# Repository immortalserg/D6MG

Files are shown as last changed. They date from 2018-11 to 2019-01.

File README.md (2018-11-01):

# D6MG shield
## Палата расширения для OrangePi PC
### Описание
- питание от источника питания 12 В
- часы реального времени i2c DS3132
- 1-wire на шине i2c DS2482
- RS485
- CAN
- выведены порты LAN и 2 USB вниз
- 315/433 МГц приемники - передатчики (2 микросхемы SYN470R, 2 микросхемы SYN115)
- nrf24l01+
- zigbee (CC2530 с усилителем CC2591)
- LoRa RFM95 (модуль)
- RFM69 (модуль)
- 16 каналов ШИМ (PCA9685)
- 16 каналов входы/выходы (MCP27013)
- 16 каналов DAC (4 микросхемы MCP4728)
- 16 каналов ADC (4 микросхемы MCP3424)
- боковой разъем c шиной i2c для подключения модулей расширения Wiren Board
- USB - UART0 СP2102
- управляемый по GPIO кулер охлаждения

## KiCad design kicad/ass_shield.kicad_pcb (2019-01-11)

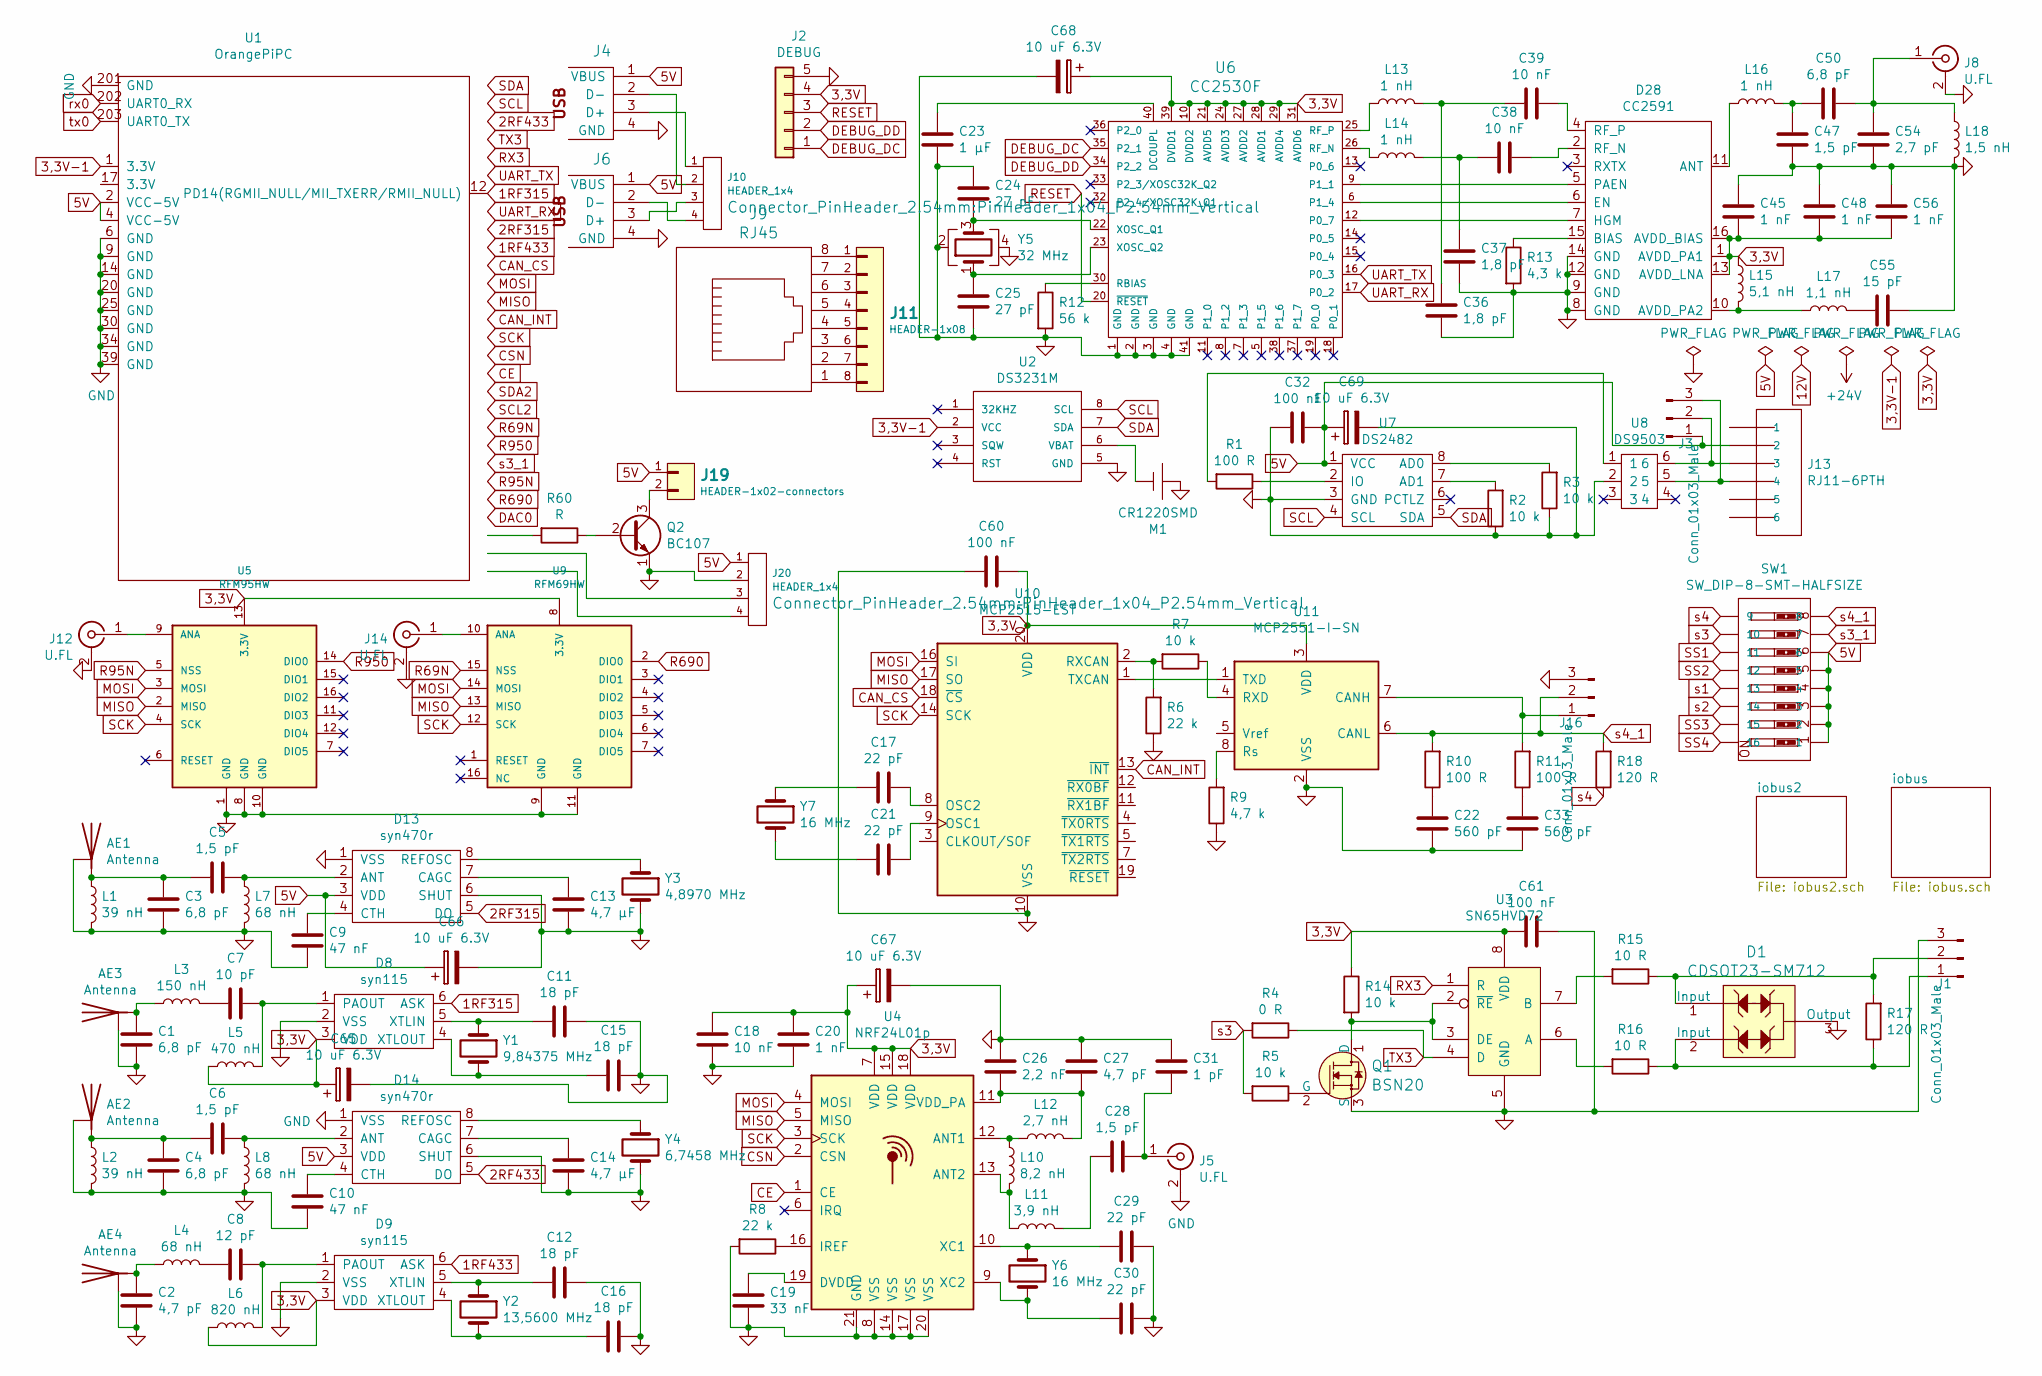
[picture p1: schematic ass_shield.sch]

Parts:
AE1, AE2, AE3, AE4: Antenna; U.FL_Hirose_U.FL-R-SMT-1_Vertical
C1, C3, C4, C50: 6,8 pF; C_0402_1005Metric
C2, C27: 4,7 pF; C_0402_1005Metric
C5, C6, C28, C47: 1,5 pF; C_0402_1005Metric
C7: 10 pF; C_0402_1005Metric
C8: 12 pF; C_0402_1005Metric
C9, C10: 47 nF; C_0402_1005Metric
C11, C12, C15, C16: 18 pF; C_0402_1005Metric
C13, C14: 4,7 µF; C_0402_1005Metric
C17, C21, C29, C30: 22 pF; C_0402_1005Metric
C18, C38, C39: 10 nF; C_0402_1005Metric
C19: 33 nF; C_0402_1005Metric
C20, C45, C48, C56: 1 nF; C_0402_1005Metric
C22, C33: 560 pF; C_0402_1005Metric
C23: 1 µF; C_0402_1005Metric
C24, C25: 27 pF; C_0402_1005Metric
C26: 2,2 nF; C_0402_1005Metric
C31: 1 pF; C_0402_1005Metric
C32, C60, C61: 100 nF; C_0402_1005Metric
C36, C37: 1,8 pF; C_0402_1005Metric
C54: 2,7 pF; C_0402_1005Metric
C55: 15 pF; C_0402_1005Metric
C65, C66, C67, C68, C69: 10 uF 6.3V; C_1206_3216Metric
D1: CDSOT23-SM712; SOT-23; MPN CDSOT23-SM712; Digi-Key_PN CDSOT23-SM712CT-ND
D8, D9: syn115; SOT-23-6_Handsoldering
D13, D14: syn470r; SSOP-8_3.95x5.21x3.27mm_P1.27mm
D28: CC2591; QFN-16-1EP_4x4mm_P0.65mm_EP2.5x2.5mm
J1, J3, J16: Conn_01x03_Male; pt_1,5-3-3,5-h
J2: DEBUG; PinHeader_1x05_P1.27mm_Vertical
J4, J6: USB; conn_usb_A-vert
J5, J8, J12, J14: U.FL; U.FL_Hirose_U.FL-R-SMT-1_Vertical
J9: RJ45; rj45-shield
J10, J20: HEADER_1x4; PinHeader_1x04_P2.54mm_Vertical
J11: HEADER-1x08; PinHeader_2x04_P2.54mm_Vertical
J13: RJ11-6PTH; rj11-shield
J19: HEADER-1x02-connectors; PinHeader_1x02_P2.54mm_Vertical
L1, L2: 39 nH; L_0402_1005Metric
L3: 150 nH; L_0402_1005Metric
L4, L7, L8: 68 nH; L_0402_1005Metric
L5: 470 nH; L_0603_1608Metric
L6: 820 nH; L_0805_2012Metric
L10: 8,2 nH; L_0402_1005Metric
L11: 3,9 nH; L_0402_1005Metric
L12: 2,7 nH; L_0402_1005Metric
L13, L14, L16: 1 nH; L_0402_1005Metric
L15: 5,1 nH; L_0402_1005Metric
L17: 1,1 nH; L_0402_1005Metric
L18: 1,5 nH; L_0402_1005Metric
M1: CR1220SMD; cr1220_smd
Q1: BSN20; SOT-23; MPN BS170; Digi-Key_PN BS170-ND
Q2: BC107; SOT-23
R1, R10, R11: 100 R; R_0402_1005Metric
R2, R3, R5, R7, R14: 10 k; R_0402_1005Metric
R4: 0 R; R_0402_1005Metric
R6, R8: 22 k; R_0402_1005Metric
R9: 4,7 k; R_0402_1005Metric
R12: 56 k; R_0402_1005Metric
R13: 4,3 k; R_0402_1005Metric
R15, R16: 10 R; R_0402_1005Metric
R17, R18: 120 R; R_0402_1005Metric
R60: R; R_0402_1005Metric
SW1: SW_DIP-8-SMT-HALFSIZE; DIPSWITCH-08-50MIL
U1: OrangePiPC
U2: DS3231M; SO-8_5.3x6.2mm_P1.27mm
U3: SN65HVD72; SOIC-8_3.9x4.9mm_P1.27mm
U4: NRF24L01p; QFN-20-1EP_4x4mm_P0.5mm_EP2.5x2.5mm
U5: RFM95HW; RFM69HW_SMD_Handsoldering
U6: CC2530F; QFN-40-1EP_6x6mm_P0.5mm_EP4.6x4.6mm
U7: DS2482; SOIC-8_3.9x4.9mm_P1.27mm
U8: DS9503; TSOT-23-6
U9: RFM69HW; RFM69HW_SMD_Handsoldering
U10: MCP2515-EST; TSSOP-20_4.4x6.5mm_P0.65mm
U11: MCP2551-I-SN; SOIC-8_3.9x4.9mm_P1.27mm
Y1: 9,84375 MHz; Crystal_HC49-4H_Vertical
Y2: 13,5600 MHz; Crystal_HC49-4H_Vertical
Y3: 4,8970 MHz; Crystal_HC49-4H_Vertical
Y4: 6,7458 MHz; Crystal_HC49-4H_Vertical
Y5: 32 MHz; Crystal_SMD_3225-4Pin_3.2x2.5mm
Y6, Y7: 16 MHz; Crystal_SMD_3215-2Pin_3.2x1.5mm

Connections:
1RF315: D8.6 (ASK), U1.12 (PD14(RGMII_NULL/MII_TXERR/RMII_NULL))
1RF433: D9.6 (ASK), U1.16
2RF315: D13.5 (DO), U1.15
2RF433: D14.5 (DO), U1.7
3,3V: C18.1, C20.1, C45.1, C48.1, C56.1, C60.1, C61.2, C65.1, C67.1, C68.1, D8.3 (VDD), D9.3 (VDD), D28.1 (AVDD_PA1), D28.13 (AVDD_LNA), D28.16 (AVDD_BIAS), J2.4, L5.1, L6.1, L15.1, R14.1, U3.8 (VDD), U4.7 (VDD), U4.15 (VDD), U4.18 (VDD), U5.13 (3.3V), U6.10 (DVDD2), U6.21 (AVDD5), U6.24 (AVDD3), U6.27 (AVDD2), U6.28 (AVDD1), U6.29 (AVDD4), U6.31 (AVDD6), U6.39 (DVDD1), U9.8 (3.3V), U10.20 (VDD), U11.3 (VDD); also elsewhere on the board
3,3V-1: U1.1 (3.3V), U2.2 (VCC)
5V: C32.1, C66.1, C69.1, D13.3 (VDD), D14.3 (VDD), J3.1, J4.1 (VBUS), J6.1 (VBUS), J13.2, J19.1, J20.1, SW1.1, SW1.2, SW1.3, SW1.4, SW1.5, SW1.6, U1.2 (VCC-5V), U1.4 (VCC-5V), U7.1 (VCC); also elsewhere on the board
CAN_CS: U1.18, U10.18 (~CS)
CAN_INT: U1.22, U10.13 (~INT)
CE: U1.26, U4.1 (CE)
CSN: U1.24, U4.2 (CSN)
DAC0: U1.36; also elsewhere on the board
DEBUG_DC: J2.1, U6.35 (P2_1)
DEBUG_DD: J2.2, U6.34 (P2_2)
GND: AE1.2 (GND), AE2.2 (GND), AE3.2 (GND), AE4.2 (GND), C1.1, C2.1, C3.2, C4.2, C9.2, C10.2, C11.1, C12.1, C13.1, C14.1, C15.1, C16.1, C18.2, C19.2, C20.2, C22.1, C23.2, C24.1, C25.2, C26.1, C27.1, C29.1, C30.1, C31.1, C32.2, C33.1, C36.2, C37.2, C45.2, C47.1, C48.2, C54.1, C55.1, C56.2, C60.2, C61.1, C65.2, C66.2, C67.2, C68.2, C69.2, D1.3 (Output), D8.2 (VSS), D9.2 (VSS), D13.1 (VSS), D13.6 (SHUT), D14.1 (VSS), D14.6 (SHUT), D28.8 (GND), D28.9 (GND), D28.12 (GND), D28.14 (GND), J1.3, J2.5, J4.4 (GND), J5.2 (Ext), J6.4 (GND), J8.2 (Ext), J12.2 (Ext), J14.2 (Ext), J16.3, J20.2, L1.2, L2.2, L7.2, L8.2, L18.2, M1.2 (+), Q1.3 (S), Q2.1 (E), R2.1, R3.1, R6.1, R8.2, R9.1, R12.2, R13.2, U1.6 (GND), U1.9 (GND), U1.14 (GND), U1.20 (GND), U1.25 (GND), U1.30 (GND), U1.34 (GND), U1.39 (GND), U1.201 (GND), U2.5 (GND), U3.5 (GND), U4.8 (VSS), U4.14 (VSS), U4.17 (VSS), U4.20 (VSS), U4.21 (GND), U5.1 (GND), U5.8 (GND), U5.10 (GND), U6.1 (GND), U6.2 (GND), U6.3 (GND), U6.4 (GND), U6.41 (GND), U7.3 (GND), U8.2, U9.9 (GND), U9.11 (GND), U10.10 (VSS), U11.2 (VSS), Y3.2, Y4.2, Y5.2, Y5.4; also elsewhere on the board
MISO: U1.21, U4.5 (MISO), U5.2 (MISO), U9.13 (MISO), U10.17 (SO)
MOSI: U1.19, U4.4 (MOSI), U5.3 (MOSI), U9.14 (MOSI), U10.16 (SI)
unnamed: AE1.1 (A), C3.1, C5.2, L1.1
unnamed: AE2.1 (A), C4.1, C6.2, L2.1
unnamed: AE3.1 (A), C1.2, L3.1
unnamed: AE4.1 (A), C2.2, L4.1
unnamed: C5.1, D13.2 (ANT), L7.1
unnamed: C6.1, D14.2 (ANT), L8.1
unnamed: C7.1, D8.1 (PAOUT), L5.2
unnamed: C7.2, L3.2
unnamed: C8.1, D9.1 (PAOUT), L6.2
unnamed: C8.2, L4.2
unnamed: C9.1, D13.4 (CTH)
unnamed: C10.1, D14.4 (CTH)
unnamed: C11.2, D8.5 (XTLIN), Y1.1
unnamed: C12.2, D9.5 (XTLIN), Y2.1
unnamed: C13.2, D13.7 (CAGC)
unnamed: C14.2, D14.7 (CAGC)
unnamed: C15.2, D8.4 (XTLOUT), Y1.2
unnamed: C16.2, D9.4 (XTLOUT), Y2.2
unnamed: C17.1, U10.8 (OSC2)
unnamed: C17.2, Y7.1
unnamed: C19.1, U4.19 (DVDD)
unnamed: C21.1, U10.9 (OSC1)
unnamed: C21.2, Y7.2
unnamed: C22.2, R10.1
unnamed: C23.1, U6.40 (DCOUPL)
unnamed: C24.2, U6.22 (XOSC_Q1), Y5.3
unnamed: C25.1, U6.23 (XOSC_Q2), Y5.1
unnamed: C26.2, C27.2, L12.2, U4.11 (VDD_PA)
unnamed: C28.1, C31.2, J5.1 (In)
unnamed: C28.2, L11.2
unnamed: C29.2, U4.10 (XC1), Y6.1
unnamed: C30.2, U4.9 (XC2), Y6.2
unnamed: C33.2, R11.1
unnamed: C36.1, C39.2, L13.2
unnamed: C37.1, C38.2, L14.2
unnamed: C38.1, D28.2 (RF_N)
unnamed: C39.1, D28.4 (RF_P)
unnamed: C47.2, C50.2, L16.2
unnamed: C50.1, C54.2, J8.1 (In), L18.1
unnamed: C55.2, L17.2
unnamed: D1.1 (Input), J1.2, R15.1, R17.2
unnamed: D1.2 (Input), J1.1, R16.1, R17.1
unnamed: D13.8 (REFOSC), Y3.1
unnamed: D14.8 (REFOSC), Y4.1
unnamed: D28.5 (PAEN), U6.9 (P1_1)
unnamed: D28.6 (EN), U6.6 (P1_4)
unnamed: D28.7 (HGM), U6.12 (P0_7)
unnamed: D28.10 (AVDD_PA2), L15.2, L17.1
unnamed: D28.11 (ANT), L16.1
unnamed: D28.15 (BIAS), R13.1
unnamed: J4.3 (D+), J10.1
unnamed: J4.2 (D-), J10.2
unnamed: J6.3 (D+), J10.3
unnamed: J6.2 (D-), J10.4
unnamed: J9.8, J11.1
unnamed: J9.7, J11.2
unnamed: J9.6, J11.3
unnamed: J9.5, J11.4
unnamed: J9.4, J11.5
unnamed: J9.3, J11.6
unnamed: J9.2, J11.7
unnamed: J9.1, J11.8
unnamed: J12.1 (In), U5.9 (ANA)
unnamed: J3.2, J13.3, U8.6
unnamed: J3.3, J13.4, U8.5
unnamed: J14.1 (In), U9.10 (ANA)
unnamed: J16.1, R11.2, U11.7 (CANH)
unnamed: J19.2, Q2.3 (C)
unnamed: J20.3, U1.38
unnamed: J20.4, U1.40
unnamed: L10.1, L12.1, U4.12 (ANT1)
unnamed: L10.2, L11.1, U4.13 (ANT2)
unnamed: L13.1, U6.25 (RF_P)
unnamed: L14.1, U6.26 (RF_N)
unnamed: M1.1 (-), U2.6 (VBAT)
unnamed: Q1.1 (D), R14.2, U3.2 (~RE), U3.3 (DE)
unnamed: Q1.2 (G), R5.1
unnamed: Q2.2 (B), R60.1
unnamed: R1.1, U7.2 (IO)
unnamed: R1.2, U8.1
unnamed: R2.2, U7.7 (AD1)
unnamed: R3.2, U7.8 (AD0)
unnamed: R6.2, R7.2, U10.2 (RXCAN)
unnamed: R7.1, U11.4 (RXD)
unnamed: R8.1, U4.16 (IREF)
unnamed: R9.2, U11.8 (Rs)
unnamed: R12.1, U6.30 (RBIAS)
unnamed: R15.2, U3.7 (B)
unnamed: R16.2, U3.6 (A)
unnamed: R60.2, U1.37
unnamed: U10.1 (TXCAN), U11.1 (TXD)
R69N: U1.29, U9.15 (NSS)
R95N: U1.33, U5.5 (NSS)
R690: U1.35, U9.2 (DIO0)
R950: U1.31, U5.14 (DIO0)
RESET: J2.3, U6.20 (~RESET)
RX3: U1.10, U3.1 (R)
SCK: U1.23, U4.3 (SCK), U5.4 (SCK), U9.12 (SCK), U10.14 (SCK)
SCL: U1.5, U2.8 (SCL), U7.4 (SCL); also elsewhere on the board
SCL2: U1.28; also elsewhere on the board
SDA: U1.3, U2.7 (SDA), U7.5 (SDA); also elsewhere on the board
SDA2: U1.27; also elsewhere on the board
SS1: SW1.11; also elsewhere on the board
SS2: SW1.12; also elsewhere on the board
SS3: SW1.15; also elsewhere on the board
SS4: SW1.16; also elsewhere on the board
TX3: R4.1, U1.8, U3.4 (D)
UART_RX: U1.13, U6.17 (P0_2)
UART_TX: U1.11, U6.16 (P0_3)
rx0: U1.202 (UART0_RX); also elsewhere on the board
s1: SW1.13; also elsewhere on the board
s2: SW1.14; also elsewhere on the board
s3: R4.2, R5.2, SW1.10
s3_1: SW1.7, U1.32
s4: R18.1, SW1.9
s4_1: J16.2, R10.2, R18.2, SW1.8, U11.6 (CANL)
tx0: U1.203 (UART0_TX); also elsewhere on the board

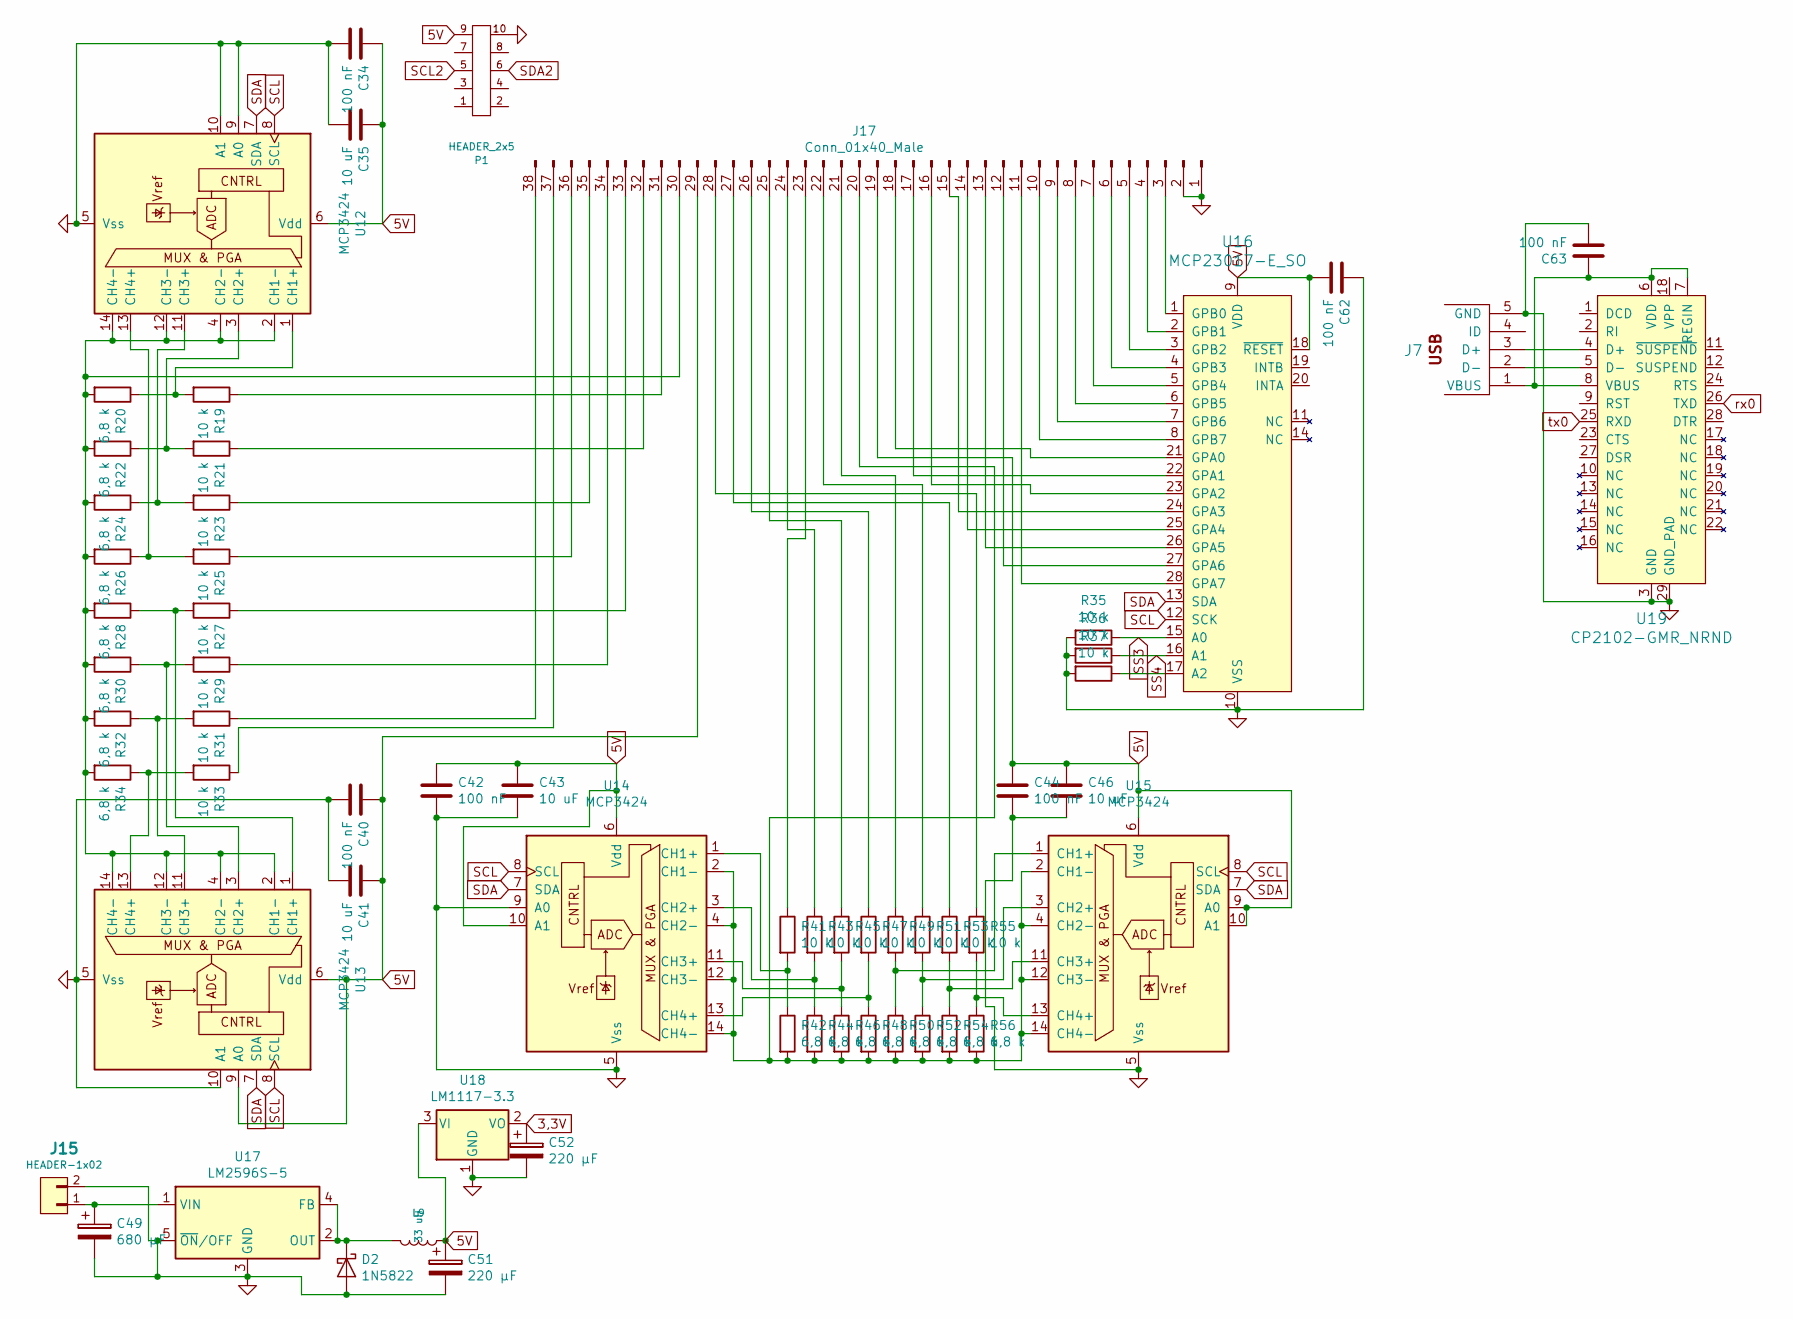
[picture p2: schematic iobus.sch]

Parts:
C34, C40, C42, C44, C62, C63: 100 nF; C_0402_1005Metric
C35, C41, C43, C46: 10 uF; C_0402_1005Metric
C49: 680 µF; CP_Elec_10x10
C51: 220 µF; CP_Elec_10x10
C52: 220 µF; C_1210_3225Metric
D2: 1N5822; D_SMC
J7: USBMINI; USB_Micro-B_Wuerth_614105150721_Vertical
J15: HEADER-1x02; mkds_1,5-2
J17: Conn_01x40_Male; PinHeader_2x19_P2.54mm_Vertical
L9: 33 uH; L_Bourns_SRR1260
P1: HEADER_2x5; PinSocket_2x05_P2.54mm_Horizontal
R19, R21, R23, R25, R27, R29, R31, R33, R35, R36, R37, R41, R43, R45, R47, R49, R51, R53, R55: 10 k; R_0402_1005Metric
R20, R22, R24, R26, R28, R30, R32, R34, R42, R44, R46, R48, R50, R52, R54, R56: 6,8 k; R_0402_1005Metric
U12, U13, U14, U15: MCP3424; TSSOP-14_4.4x5mm_P0.65mm
U16: MCP23017-E_SO; SOIC-28W_7.5x17.9mm_P1.27mm; MPN MCP23017-E/SO; Digi-Key_PN MCP23017-E/SO-ND
U17: LM2596S-5; TO-263-5_TabPin3
U18: LM1117-3.3; SOT-223
U19: CP2102-GMR_NRND; QFN-28-1EP_5x5mm_P0.5mm_EP3.35x3.35mm; MPN CP2102-GMR; Digi-Key_PN 336-1160-1-ND

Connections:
3,3V: C52.1, U18.2 (VO); also elsewhere on the board
5V: C34.1, C35.1, C40.1, C41.1, C42.1, C43.1, C44.1, C46.1, C51.1, C62.2, J17.19, J17.29, L9.1, P1.9, U12.6 (Vdd), U13.6 (Vdd), U13.9 (A0), U14.6 (Vdd), U14.10 (A1), U15.6 (Vdd), U15.9 (A0), U15.10 (A1), U16.9 (VDD), U16.18 (~RESET), U18.3 (VI); also elsewhere on the board
GND: C34.2, C35.2, C40.2, C41.2, C42.2, C43.2, C44.2, C46.2, C49.2, C51.2, C52.2, C62.1, C63.2, D2.2 (A), J7.5 (GND), J15.2, J17.1, J17.2, P1.10, R35.2, R36.2, R37.2, U12.5 (Vss), U12.9 (A0), U12.10 (A1), U13.5 (Vss), U13.10 (A1), U14.5 (Vss), U14.9 (A0), U15.5 (Vss), U16.10 (VSS), U17.3 (GND), U17.5 (~ON~/OFF), U18.1 (GND), U19.3 (GND), U19.29 (GND_PAD); also elsewhere on the board
unnamed: C49.1, J15.1, U17.1 (VIN)
unnamed: C63.1, J7.1 (VBUS), U19.6 (VDD), U19.7 (REGIN), U19.8 (VBUS)
unnamed: D2.1 (K), L9.2, U17.2 (OUT), U17.4 (FB)
unnamed: J7.2 (D-), U19.5 (D-)
unnamed: J7.3 (D+), U19.4 (D+)
unnamed: J17.3, U16.1 (GPB0)
unnamed: J17.4, U16.2 (GPB1)
unnamed: J17.5, U16.3 (GPB2)
unnamed: J17.6, U16.4 (GPB3)
unnamed: J17.7, U16.5 (GPB4)
unnamed: J17.8, U16.6 (GPB5)
unnamed: J17.9, U16.7 (GPB6)
unnamed: J17.10, U16.8 (GPB7)
unnamed: J17.11, U16.28 (GPA7)
unnamed: J17.12, U16.27 (GPA6)
unnamed: J17.13, U16.26 (GPA5)
unnamed: J17.14, U16.25 (GPA4)
unnamed: J17.15, U16.24 (GPA3)
unnamed: J17.16, U16.23 (GPA2)
unnamed: J17.17, U16.22 (GPA1)
unnamed: J17.18, U16.21 (GPA0)
unnamed: J17.20, R42.2, R44.2, R46.2, R48.2, R50.2, R52.2, R54.2, R56.2, U14.2 (CH1-), U14.4 (CH2-), U14.12 (CH3-), U14.14 (CH4-), U15.2 (CH1-), U15.4 (CH2-), U15.12 (CH3-), U15.14 (CH4-)
unnamed: J17.21, R49.1
unnamed: J17.22, R51.1
unnamed: J17.23, R41.1
unnamed: J17.24, R43.1
unnamed: J17.25, R45.1
unnamed: J17.26, R47.1
unnamed: J17.27, R53.1
unnamed: J17.28, R55.1
unnamed: J17.30, R20.2, R22.2, R24.2, R26.2, R28.2, R30.2, R32.2, R34.2, U12.2 (CH1-), U12.4 (CH2-), U12.12 (CH3-), U12.14 (CH4-), U13.2 (CH1-), U13.4 (CH2-), U13.12 (CH3-), U13.14 (CH4-)
unnamed: J17.31, R19.1
unnamed: J17.32, R21.1
unnamed: J17.33, R27.1
unnamed: J17.34, R29.1
unnamed: J17.35, R23.1
unnamed: J17.36, R25.1
unnamed: J17.37, R33.1
unnamed: J17.38, R31.1
unnamed: R19.2, R20.1, U12.1 (CH1+)
unnamed: R21.2, R22.1, U12.3 (CH2+)
unnamed: R23.2, R24.1, U12.11 (CH3+)
unnamed: R25.2, R26.1, U12.13 (CH4+)
unnamed: R27.2, R28.1, U13.1 (CH1+)
unnamed: R29.2, R30.1, U13.3 (CH2+)
unnamed: R31.2, R32.1, U13.11 (CH3+)
unnamed: R33.2, R34.1, U13.13 (CH4+)
unnamed: R37.1, U16.17 (A2)
unnamed: R41.2, R42.1, U14.1 (CH1+)
unnamed: R43.2, R44.1, U14.3 (CH2+)
unnamed: R45.2, R46.1, U14.11 (CH3+)
unnamed: R47.2, R48.1, U14.13 (CH4+)
unnamed: R49.2, R50.1, U15.1 (CH1+)
unnamed: R51.2, R52.1, U15.3 (CH2+)
unnamed: R53.2, R54.1, U15.11 (CH3+)
unnamed: R55.2, R56.1, U15.13 (CH4+)
SCL: U12.8 (SCL), U13.8 (SCL), U14.8 (SCL), U15.8 (SCL), U16.12 (SCK); also elsewhere on the board
SCL2: P1.5; also elsewhere on the board
SDA: U12.7 (SDA), U13.7 (SDA), U14.7 (SDA), U15.7 (SDA), U16.13 (SDA); also elsewhere on the board
SDA2: P1.6; also elsewhere on the board
SS3: R35.1, U16.15 (A0); also elsewhere on the board
SS4: R36.1, U16.16 (A1); also elsewhere on the board
rx0: U19.26 (TXD); also elsewhere on the board
tx0: U19.25 (RXD); also elsewhere on the board

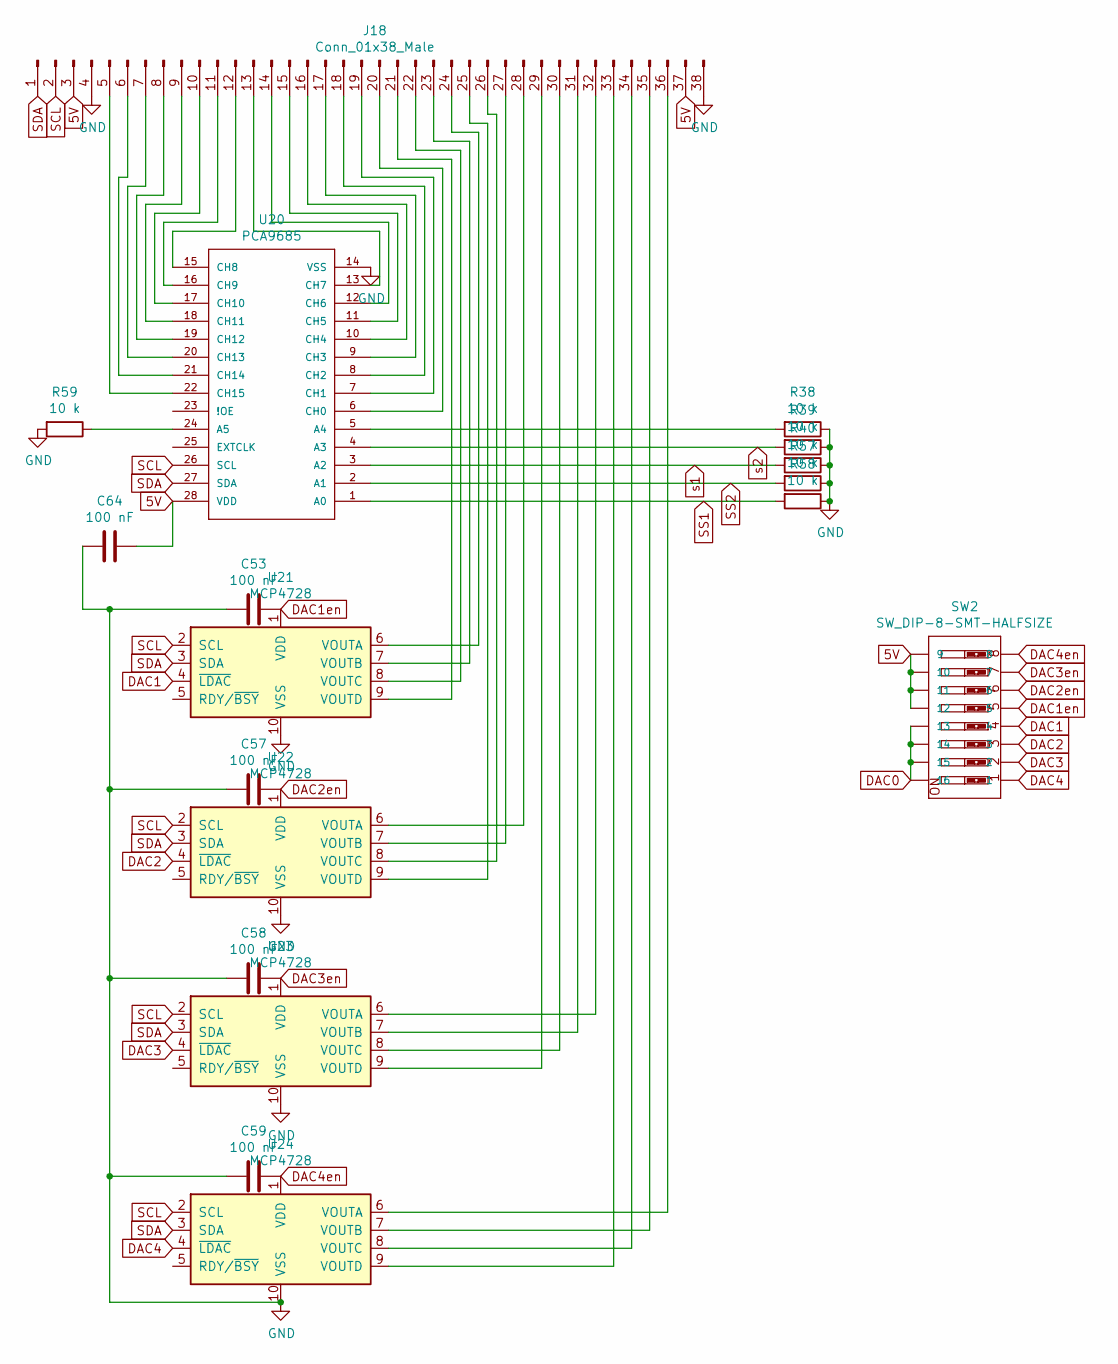
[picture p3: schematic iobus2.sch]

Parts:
C53, C57, C58, C59, C64: 100 nF; C_0402_1005Metric
J18: Conn_01x38_Male; PinHeader_2x19_P2.54mm_Vertical
R38, R39, R40, R57, R58, R59: 10 k; R_0402_1005Metric
SW2: SW_DIP-8-SMT-HALFSIZE; DIPSWITCH-08-50MIL
U20: PCA9685; TSSOP-28_4.4x9.7mm_P0.65mm
U21, U22, U23, U24: MCP4728; MSOP-10_3x3mm_P0.5mm

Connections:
5V: C64.1, J18.3, J18.37, SW2.9, SW2.10, SW2.11, SW2.12, U20.28 (VDD); also elsewhere on the board
DAC0: SW2.13, SW2.14, SW2.15, SW2.16; also elsewhere on the board
DAC1: SW2.4, U21.4 (~LDAC)
DAC1en: C53.1, SW2.5, U21.1 (VDD)
DAC2: SW2.3, U22.4 (~LDAC)
DAC2en: C57.1, SW2.6, U22.1 (VDD)
DAC3: SW2.2, U23.4 (~LDAC)
DAC3en: C58.1, SW2.7, U23.1 (VDD)
DAC4: SW2.1, U24.4 (~LDAC)
DAC4en: C59.1, SW2.8, U24.1 (VDD)
GND: C53.2, C57.2, C58.2, C59.2, C64.2, J18.4, J18.38, R38.1, R39.1, R40.1, R57.1, R58.1, R59.2, U20.14 (VSS), U21.10 (VSS), U22.10 (VSS), U23.10 (VSS), U24.10 (VSS); also elsewhere on the board
unnamed: J18.5, U20.22 (CH15)
unnamed: J18.6, U20.21 (CH14)
unnamed: J18.7, U20.20 (CH13)
unnamed: J18.8, U20.19 (CH12)
unnamed: J18.9, U20.18 (CH11)
unnamed: J18.10, U20.17 (CH10)
unnamed: J18.11, U20.16 (CH9)
unnamed: J18.12, U20.15 (CH8)
unnamed: J18.13, U20.13 (CH7)
unnamed: J18.14, U20.12 (CH6)
unnamed: J18.15, U20.11 (CH5)
unnamed: J18.16, U20.10 (CH4)
unnamed: J18.17, U20.9 (CH3)
unnamed: J18.18, U20.8 (CH2)
unnamed: J18.19, U20.7 (CH1)
unnamed: J18.20, U20.6 (CH0)
unnamed: J18.21, U21.9 (VOUTD)
unnamed: J18.22, U21.8 (VOUTC)
unnamed: J18.23, U21.7 (VOUTB)
unnamed: J18.24, U21.6 (VOUTA)
unnamed: J18.25, U22.9 (VOUTD)
unnamed: J18.26, U22.8 (VOUTC)
unnamed: J18.27, U22.7 (VOUTB)
unnamed: J18.28, U22.6 (VOUTA)
unnamed: J18.29, U23.9 (VOUTD)
unnamed: J18.30, U23.8 (VOUTC)
unnamed: J18.31, U23.7 (VOUTB)
unnamed: J18.32, U23.6 (VOUTA)
unnamed: J18.33, U24.9 (VOUTD)
unnamed: J18.34, U24.8 (VOUTC)
unnamed: J18.35, U24.7 (VOUTB)
unnamed: J18.36, U24.6 (VOUTA)
unnamed: R38.2, U20.5 (A4)
unnamed: R59.1, U20.24 (A5)
SCL: J18.2, U20.26 (SCL), U21.2 (SCL), U22.2 (SCL), U23.2 (SCL), U24.2 (SCL); also elsewhere on the board
SDA: J18.1, U20.27 (SDA), U21.3 (SDA), U22.3 (SDA), U23.3 (SDA), U24.3 (SDA); also elsewhere on the board
SS1: R58.2, U20.1 (A0); also elsewhere on the board
SS2: R57.2, U20.2 (A1); also elsewhere on the board
s1: R40.2, U20.3 (A2); also elsewhere on the board
s2: R39.2, U20.4 (A3); also elsewhere on the board

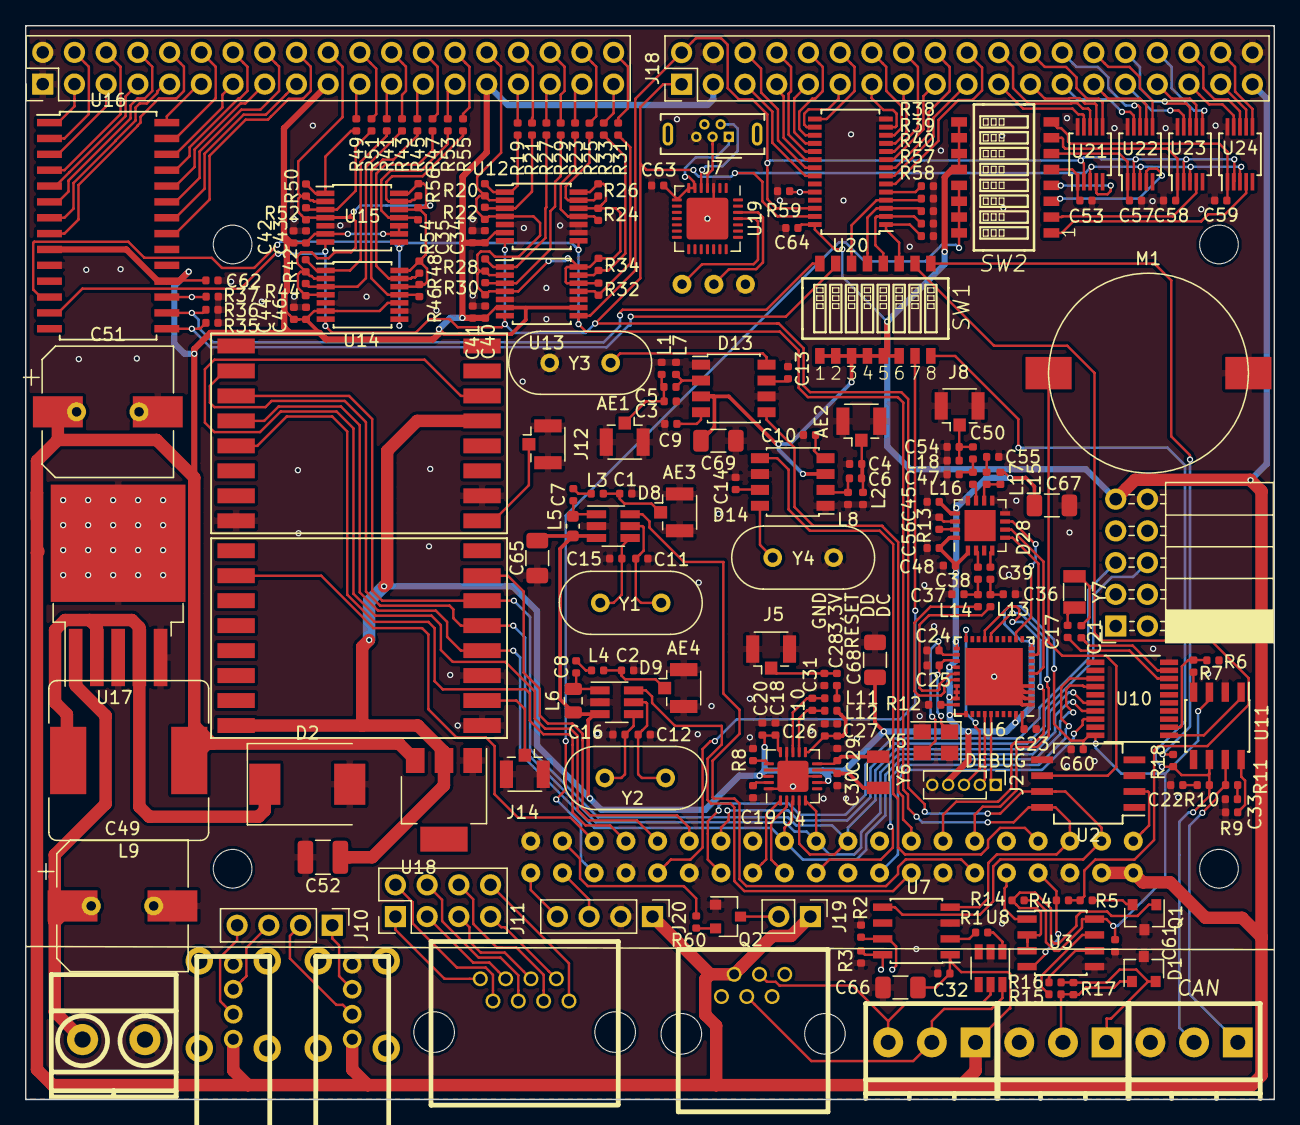
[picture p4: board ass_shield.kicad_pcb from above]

Board: 2 copper layers, 100.0 x 86.0 mm, 215 parts (0 on the bottom side), 232 nets.

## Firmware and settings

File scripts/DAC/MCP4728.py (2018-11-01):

#!/usr/bin/env python
"""
================================================
MCP4728 DAC

Marko Pinteric 2018
http://www.pinteric.com/raspberry.html

Requires python smbus to be installed
================================================
"""

try:
    import smbus
except ImportError:
    raise ImportError("python-smbus not found")

import RPi.GPIO as GPIO
import re
import platform
import time

class MCP4728:
    """
    Control the MCP4728 DAC
    """
    # internal variables
    __dac_address = 0x60
    __bus = None

    # local methods
    @staticmethod
    def __get_smbus():
        """
        internal method for getting an instance of the i2c bus
        copied from ABElectronics ADC Differential Pi 8-Channel ADC
        """
        i2c__bus = 1
        # detect the device that is being used
        device = platform.uname()[1]

        if device == "orangepione":  # running on orange pi one
            i2c__bus = 0

        elif device == "orangepiplus":  # running on orange pi one
            i2c__bus = 0

        elif device == "linaro-alip":  # running on Asus Tinker Board
            i2c__bus = 1

        elif device == "raspberrypi":  # running on raspberry pi
            # detect i2C port number and assign to i2c__bus
            for line in open('/proc/cpuinfo').readlines():
                model = re.match('(.*?)\\s*\\s*(.*)', line)
                if model:
                    (name, value) = (model.group(1), model.group(2))
                    if name == "Revision":
                        if value[-4:] in ('0002', '0003'):
                            i2c__bus = 0
                        else:
                            i2c__bus = 1
                        break
        try:
            return smbus.SMBus(i2c__bus)
        except IOError:
            raise 'Could not open the i2c bus'

    def __updatebyte(self, byte, mask, value):
        byte &= mask
        byte |= value
        return byte

    # init object with i2caddress, default is 0x60 for MCP4728
    def __init__(self, address=0x60):
        self.__bus = self.__get_smbus()
        self.__dac_address = address
        GPIO.setmode(GPIO.BCM)
        GPIO.setwarnings(False)

    def single_raw(self, channel, reference, gain, value):
        """
        writes single raw value to the selected DAC channel - channels 1 to 4
        """
        second, third = divmod(value, 0x100)
        first=self.__updatebyte(0x58,0xFF,(channel-1) << 1)
        second=self.__updatebyte(second,0x0F,reference << 7 | gain << 4)
        self.__bus.write_i2c_block_data(self.__dac_address,first,[second, third])
        return

    def single_internal(self, channel, volt):
        """
        writes single value to the selected DAC channel using internal reference - channels 1 to 4
        """
        if volt>2: gain=2
        else: gain=1
        value=int(0x1000 * volt/2.048/gain)
        self.single_raw(channel,1,gain-1,value)

    def single_external(self, channel, rel):
        """
        writes single value to the selected DAC channel using external reference - channels 1 to 4
        """
        value=int(0x1000 * rel)
        self.single_raw(channel,0,0,value)


class MCP4728_address:
    """
    Gets and sets the MCP4728 DAC address
    """
    # local methods
    # all assume and leave SCL low, except when specified differently
    
    # assumes SCL and SDA high
    def __i2cstart(self):
        GPIO.setup(self.__sda_gpio, GPIO.OUT, initial=GPIO.LOW)
        GPIO.setup(self.__scl_gpio, GPIO.OUT, initial=GPIO.LOW)

    def __i2crestart(self):
        GPIO.setup(self.__sda_gpio, GPIO.IN)
        GPIO.setup(self.__scl_gpio, GPIO.IN)
        GPIO.setup(self.__sda_gpio, GPIO.OUT, initial=GPIO.LOW)
        GPIO.setup(self.__scl_gpio, GPIO.OUT, initial=GPIO.LOW)

    # leaves SCL and SDA high
    def __i2cstop(self):
        GPIO.setup(self.__sda_gpio, GPIO.OUT, initial=GPIO.LOW)
        GPIO.setup(self.__scl_gpio, GPIO.IN)
        GPIO.setup(self.__sda_gpio, GPIO.IN)

    def __i2cgetbyte(self):
        num=0x00
        GPIO.setup(self.__sda_gpio, GPIO.IN)
        for i in range(8):
            GPIO.setup(self.__scl_gpio, GPIO.IN)
            # clock stretching
            while(GPIO.input(self.__scl_gpio)==False): time.sleep(0.000001)
            num = num << 1
            if(GPIO.input(self.__sda_gpio)==True): num = num | 0x01
            GPIO.setup(self.__scl_gpio, GPIO.OUT, initial=GPIO.LOW)
        #print('Getting: {0:08b}'.format( num )) # for testing purposes
        return(num)

    def __i2csendbyte(self,num):
        #print('Sending: {0:08b}'.format( num )) # for testing purposes
        for i in range(8):
            if num & 0x80 == 0:
                GPIO.setup(self.__sda_gpio, GPIO.OUT, initial=GPIO.LOW)
            else:
                GPIO.setup(self.__sda_gpio, GPIO.IN)
            num = num << 1
            GPIO.setup(self.__scl_gpio, GPIO.IN)
            GPIO.setup(self.__scl_gpio, GPIO.OUT, initial=GPIO.LOW)

    def __i2cgetack(self):
        GPIO.setup(self.__sda_gpio, GPIO.IN)
        GPIO.setup(self.__scl_gpio, GPIO.IN)
        res=GPIO.input(self.__sda_gpio)
        GPIO.setup(self.__scl_gpio, GPIO.OUT, initial=GPIO.LOW)
        return(not res)

    def __i2csendack(self):
        GPIO.setup(self.__sda_gpio, GPIO.OUT, initial=GPIO.LOW)
        GPIO.setup(self.__scl_gpio, GPIO.IN)
        GPIO.setup(self.__scl_gpio, GPIO.OUT, initial=GPIO.LOW)

    def __i2csendnack(self):
        GPIO.setup(self.__sda_gpio, GPIO.IN)
        GPIO.setup(self.__scl_gpio, GPIO.IN)
        GPIO.setup(self.__scl_gpio, GPIO.OUT, initial=GPIO.LOW)

    # init object with GPIO addresses
    def __init__(self, scl, sda, ldac):
        self.__scl_gpio=scl
        self.__sda_gpio=sda
        self.__ldac_gpio=ldac
        GPIO.setmode(GPIO.BCM)
        GPIO.setwarnings(False)

    def getaddress(self):
        """
        gets the DAC address
        """
        GPIO.setup(self.__scl_gpio, GPIO.IN)
        GPIO.setup(self.__sda_gpio, GPIO.IN)
        GPIO.setup(self.__ldac_gpio, GPIO.IN)

        self.__i2cstart()
        self.__i2csendbyte(0)
        if(self.__i2cgetack()==False): print('No ACK G1')
        self.__i2csendbyte(0x0C)
        GPIO.setup(self.__ldac_gpio, GPIO.OUT, initial=GPIO.LOW)
        if(self.__i2cgetack()==False): print('No ACK G2')
        self.__i2crestart()
        self.__i2csendbyte(0xC1)
        GPIO.setup(self.__ldac_gpio, GPIO.IN)
        if(self.__i2cgetack()==False): print('No ACK G3')
        val = self.__i2cgetbyte()
        self.__i2csendnack()
        self.__i2cstop()
        adr1 = (val & 0xE0) >> 5
        adr2 = (val & 0x0E) >> 1
        if ((adr1 != adr2) or ((val & 0x11) != 0x10)):
            print('Error: returned {0:08b}'.format(val))
        return(0xC0 | adr1)
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
